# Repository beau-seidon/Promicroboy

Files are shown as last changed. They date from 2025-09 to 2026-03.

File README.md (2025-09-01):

# Arduinoboy (b_s)
~~Official~~ ArduinoBoy Repository for serial MIDI communication to the Nintendo Gameboy.

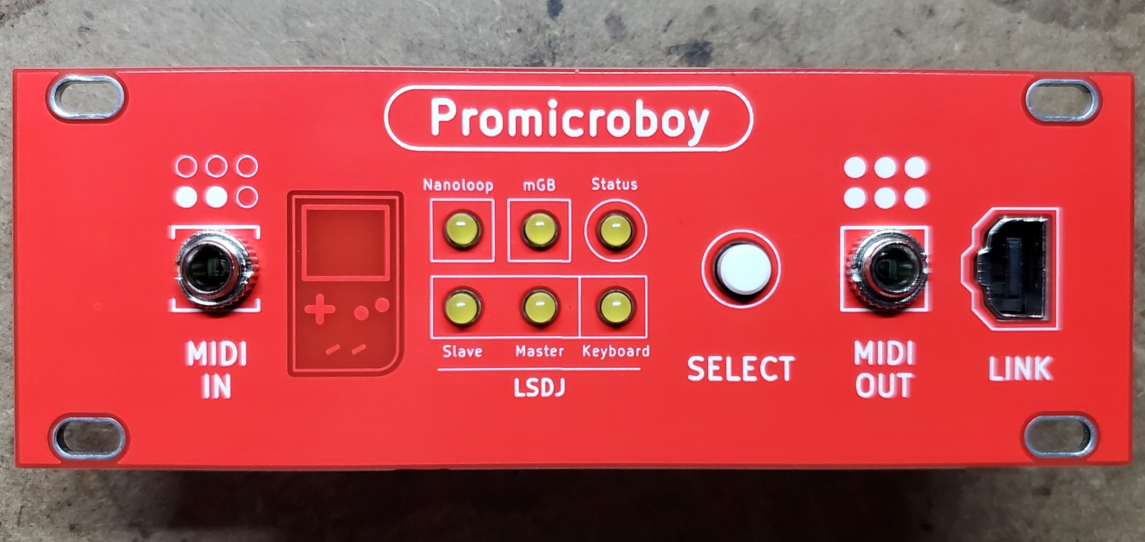
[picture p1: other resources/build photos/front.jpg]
Promicroboy


### The readme below is still based on the original repo, updates coming soon!
See changelog for more info.



## About
Arduinoboy is software for the [Arduino hardware platform](http://arduino.cc) that allows serial communication (MIDI) to the Nintendo Gameboy for music applications such as [LittleSoundDJ](http://littlesounddj.com), [Nanoloop.](http://www.nanoloop.com/), and [mGB](https://github.com/trash80/mGB)

## Current Features
* Affordable and easily accessible parts for assembly.
* Accurate MIDI Sync, Start and Stop commands.
* Push Button selector sets the sync/state modes [(7 modes available)](#modes-details)
* [mGB](https://github.com/trash80/mGB)
 Mode: Full MIDI in support across all Gameboy Channels, including a unique "poly" mode allows you to play your Game Boy like a synthesizer.
* Midi Out Doubles as a Midi Thru
* "Filtering" data for only sync messages, no dedicated MIDI line required.
* Can be powered by the Game Boy's gamelink port.
* USB upgradeable via Arduino.
* Midi settings configurable using a Mac/PC editor built in Max.
* Tested and works with DMG (Original), Gameboy Color, and Advance/SP.

## Modes Details
#### Mode 1 - LSDJ as MIDI Slave Sync
Slave your Game Boy running [LittleSoundDJ](http://littlesounddj.com) to your midi sequencer or Digital audio workstation.

You can send the arduinoboy midi notes to change sync resolution and start/stop the LSDJ sequencer.

_LSDJ Slave Mode Midi Note Effects:_

* 48 - `C-2` Sends a Sequencer Start Command
* 49 - `C#2` Sends a Sequencer Stop Command
* 50 - `D-2` Toggles Normal Tempo
* 51 - `D#2` Toggles 1/2 Tempo
* 52 - `E-2` Toggles 1/4 Tempo
* 53 - `F-2` Toggles 1/8 Tempo

Higher note values than these map LSDJ song position row offset on a Song Start.

In LSDJ the `sync` mode should be set to `Slave`

#### Mode 2 LSDJ as MIDI Master Sync.

Send Midi sync with LSDJ as a midi clock master, LSDJ also sends a Midi Note on message that corresponds to the song row number on play.

In LSDJ the `sync` mode should be set to `Master`

#### Mode 3 LSDJ PC Keyboard mode.
This mode emulates the [PC Keyboard Mode](http://littlesounddj.wikia.com/wiki/PC_Keyboard_Interface) built into LSDJ, allowing you to control the following aspects of LSDJ:

Features:

* The first octave controls M-U-T-E,
* Cursor control (LSDJ Live mode only),
* Table selection
* Table cue.

_PC Keyboard mode midi note map_

* 36 - `C-1` Mute Pu1 Off/On
* 37 - `C#1` Mute Pu2 Off/On
* 38 - `D-1` Mute Wav Off/On
* 39 - `D#1` Mute Noi Off/On
* 40 - `E-1` Livemode Cue Sequence
* 41 - `F-1` Livemode Cursor Up
* 42 - `F#1` Livemode Cursor Down
* 43 - `G-1` Livemode Cursor Left
* 44 - `G#1` Live mode Cursor Right
* 45 - `A-1` Table Up
* 46 - `A#1` Table Down
* 47 - `B-1` Cue Table
* 48+ - Notes from this note up will accept midi in from an external keyboard or sequencer and allow you to play the notes`C-2 to C-8`.
* Midi Program Change messages will select from instrument table
* Default Midi channel is 16. You can set this in the top of the main source file in the archive, or via the [Max Pat editor](#max).

In LSDJ the `sync` mode should be set to `Keyboard`

#### Mode 4 MIDI to Nanoloop sync
Sync [Nanoloop.](http://www.nanoloop.com/) to external midi clock signals sent to the midi in.

In Nanoloop, the sync mode should be set to `slave`.

#### Mode 5 Full MIDI with mGB
[mGB](https://github.com/trash80/mGB) is a Gameboy cartridge program (You need a Flash Cart and Transfer hardware) That enables the Gameboy to act as a MIDI supported sound module that allows full control of the Game Boy sound hardware.

It works with the old DMG Gameboy as well as GBC/GBA.

#### Mode 6 LSDJ MIDIMAP
Lsdj will sync to incoming MIDI sync, and incoming MIDI notes are mapped to LSDJ's song row #. The currently selected row's MIDI note is displayed on the top right of the LSDJ screen, and incoming MIDI notes will also display the relative song row number in the same location.

In LSDJ the `sync` mode should be set to `MI.MAP`.

*This requires a special version of LSDJ, which can be found in your account on the [LSDJ website](http://littlesounddj.com/lsd/latest/full_version/).*

#### Mode 7 LSDJ MIDIOUT
Each of the 4 gameboy channels send MIDI data on 4 midi channels by the use of effects commands:

* `Nxx` - Sends a MIDI Note - Absolute to the value placed in the effect. N00 sends note off, `N01`-`N6F` send midi notes 1 to 112.
* `Qxx` - Sends a [MIDI Note](http://www.electronics.dit.ie/staff/tscarff/Music_technology/midi/midi_note_numbers_for_octaves.htm) relative to the current channel's pitch. The effect value is a offset. so `Q0C` in `PU1` would send a note 1 octave higher than what `PU1` is currently playing. This is useful as a table command to track midi notes as normal notes in the sequencer.
* `Xxx` - Sends a MIDI CC - By default in Arduinoboy the high nibble selects a CC#, and the low nibble sends a value `0-F` to `0-127`. This can be changed to allow just 1 midi CC with a range of `00`-`6F`, or 7 CCs with scaled or unscaled values.
* `Yxx` - Sends a program/patch/preset change.

By default each channel of LSDJ is mapped to midi channels 1-4. For example note commands from PU1 will be sent to midi channel 1.

In LSDJ the `sync` mode should be set to `Midiout`.

*This requires a special version of LSDJ, which can be found in your account on the [LSDJ website](http://littlesounddj.com/lsd/latest/full_version/).*

## Max Editor
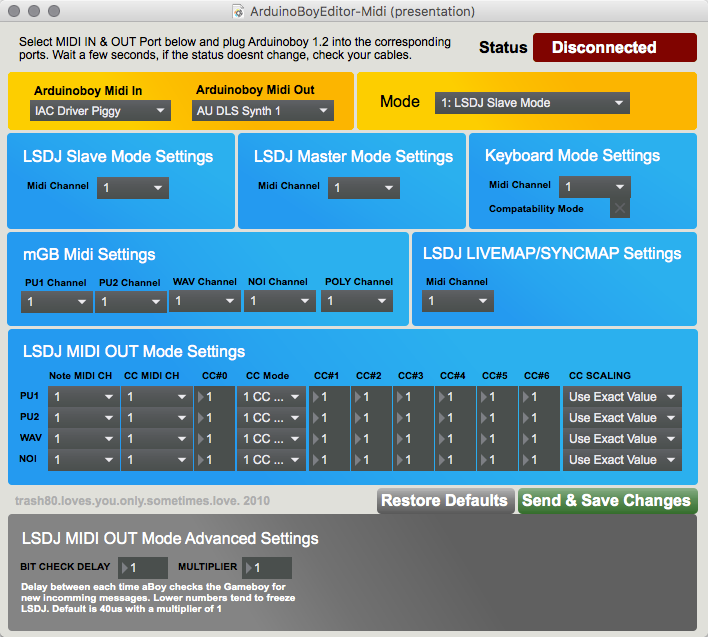
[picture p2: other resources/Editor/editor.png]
Editor gui

[The Arduinoboy Editor for Max](https://github.com/trash80/Arduinoboy/tree/master/Editor) for PC/OSX machines is a gui editor that allows you to edit the various global midi settings of your arduinoboy without editing or flashing code, over midi. It used to required the now deprecated Max Runtime, but you can also run it using a demo of [Cycling '74's Max application](https://cycling74.com/downloads/)

### Maxpat Settings
* `Midi In/Out`
Connect your arduinoboy to these ports on your system. Once it has connected, all the lights on your arduinoboy should flash in order, and the editor will show a green `Connected`.
* `Mode`
Setting this will tell your arduinoboy what mode to boot into automatically. This is handy if you built your own arduinoboy and decided you wanted to skimp out on LEDs and a button.
* `LSDJ Slave Mode settings` - The midi channel LSDJ slave mode will receive its commands on.
* `LSDJ Master Mode settings` - The midi channel LSDJ Master mode will send its midi notes mapped to row number on.
* `Keyboard Mode settings` - What channel LSDJ will look for its keyboard mode midi commands. No idea what compatibility mode does.
* `mGB midi settings` - Map each incoming midi channel to a specific Gameboy channel in mGB.
* `LSDJ Livesync/Livemap settings` - The midi channel Livesync/Livemap will listen to incoming midi commands from.
* `LSDJ Midiout settings` - Here you can set the following:
	* `Note midi channel` -  The channel each LSDJ channel will send it's midi note commands on.
	* `CC midi channel` -  The channel each LSDJ channel will send it's Continuous Controller commands on.
	* `CC 0` - The initial CC each channel will send. The type of data it will send is based on the next setting.
	* `CC Mode` - Game Boys have limitations! You can either have arduinoboy send one CC with many values, or 7 with limited 8bit values. By default in Arduinoboy the high nibble selects a CC#, and the low nibble sends a value [0-F] to [0-127]. This can be changed to allow just 1 midi CC with a range of 00-6F, or 7 CCs with scaled or unscaled values.
	* `CC Scaling ` - Set wether the 7 CCs are scaled or unscaled.

## Future Features & wishlist
  * Build instructions, and a Arduino Shield

## How To build an Arduinoboy



* [Build Photos](http://flickr.com/photos/trash80/2316803175/in/set-72157604068871573/)
* [Old version (Pre 1.1.0)](http://trash80.net/junkfood/arduinoboy/arduinoboy-schem-v.0.9.8-r1.png)

### Video Demos

  * [Keyboard Mode Test](http://youtube.com/watch?v=TnLUuvc78XY)
  * [Sync Demos](http://youtube.com/watch?v=iVmhy-Lo7BI)
  * [Arduino inside of Gameboy DMG](http://youtube.com/watch?v=VwrMuOA0VnY)
  * [mGB Example & Arduinoboy build into a DMG](http://vimeo.com/1853931)
  * [PDF explores mGB with a MIDI guitar](http://www.youtube.com/watch?v=HAU9MzZ2qeE)

## Thanks To
  * [Arduino](http://arduino.cc)
  * [Nitro2k01](http://blog.gg8.se/wordpress/) for ASM help with mGB
  * [GWEM](http://www.preromanbritain.com/gwem/lsdj_midi/g33k.html) g33k page
  * [Midines](http://wayfar.net) Thanks for the help x|k!
  * [firestARTer](http://www.firestarter-music.de) help with keyboard & Midi handling information.
  * [Gijs Gieskes](http://gieskes.nl) Found source code that gave insight into Nanoloop sync
  * [Little Sound DJ](http://littlesounddj.com)
  * [http://devrs.com/gb](http://devrs.com/gb) Madcatz PC link port for gb serial specs
  * [http://chipmusic.org](http://chipmusic.org) For all things Chipmusic.

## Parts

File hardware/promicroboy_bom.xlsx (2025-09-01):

REF | QTY | VAL | MOUSER | OTHER
C1 | 1 | 0.47 uF | 603-CC805JRNPO9BN471 (https://www.mouser.com/ProductDetail/603-CC805JRNPO9BN471)
C2 | 1 | 22 uF | 187-CL31A226KAHNNNE (https://www.mouser.com/ProductDetail/187-CL31A226KAHNNNE)
D1-D6 | 6 | 3 mm, yellow | 710-151031YS06000 (https://www.mouser.com/ProductDetail/710-151031YS06000)
D7 | 1 | 1N4148W | 833-1N4148W-TP (https://www.mouser.com/ProductDetail/833-1N4148W-TP)
J1-J2 | 2 | 3.5 mm TRS |  | PJ366ST/ WQP518MA (stereo)/ PJ398SM (https://www.thonk.co.uk/shop/thonkiconn/)
J3 | 1 | 02x05, male | 710-61301021121 (https://www.mouser.com/ProductDetail/710-61301021121)
J4a | 1 | 01x06, male, right-angle | 649-68015-406HLF (https://www.mouser.com/ProductDetail/649-68015-406HLF)
J4b | 1 | GB Link Port |  | Link Port (https://handheldlegend.com/products/game-boy-advance-ext-link-port)
R1-R4 | 4 | 220R | 603-RC0805FR-07220RL (https://www.mouser.com/ProductDetail/603-RC0805FR-07220RL)
R5 | 1 | 4.7K | 603-RC0805FR-074K7L (https://www.mouser.com/ProductDetail/603-RC0805FR-074K7L)
R6 | 1 | 2K | 603-RC0805FR-072KL (https://www.mouser.com/ProductDetail/603-RC0805FR-072KL)
R7-R12 | 6 | 1K | 603-RC0805FR-071KL (https://www.mouser.com/ProductDetail/603-RC0805FR-071KL)
SW1a | 1 | 6 mm | 612-105SPF100Q1RBLK (https://www.mouser.com/ProductDetail/612-105SPF100Q1RBLK)
SW1b | 1 | Round White | 612-1RWHT (https://www.mouser.com/ProductDetail/612-1RWHT)
U1a | 1 | ProMicro, 5v, 16MHz |  | Sparkfun ProMicro 5V 16MHz (https://www.sparkfun.com/pro-micro-5v-16mhz.html)
U1b | 2 | 01x12, female |  | Female Headers (https://www.sparkfun.com/female-headers.html)
U2a | 1 | 6N138 | 859-6N138 (https://www.mouser.com/ProductDetail/859-6N138)
U2b | 1 | PDIP8 | 571-2485264-1 (https://www.mouser.com/ProductDetail/571-2485264-1)
U3 | 1 | +8 VDC | 926-LM2940IMPX80NOPB (https://www.mouser.com/ProductDetail/926-LM2940IMPX80NOPB)

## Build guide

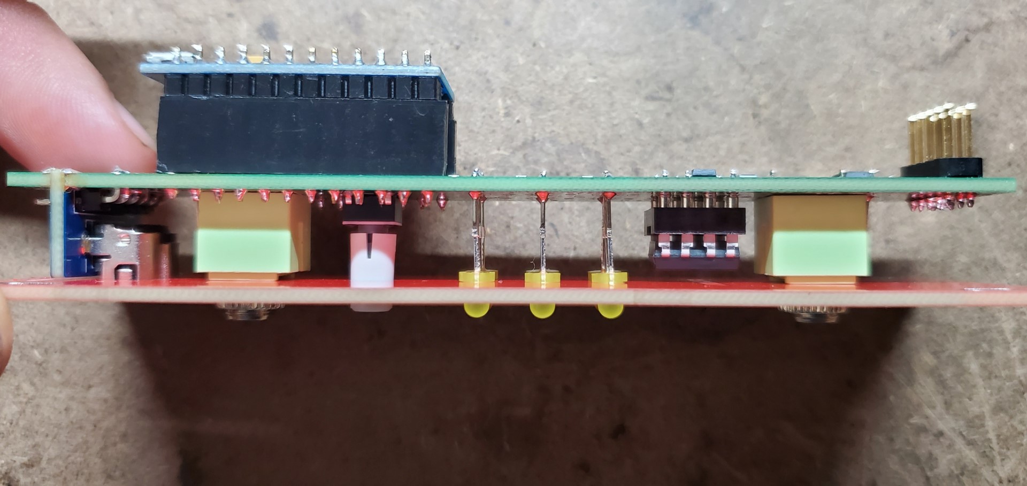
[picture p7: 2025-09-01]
other resources/build photos/side.jpg

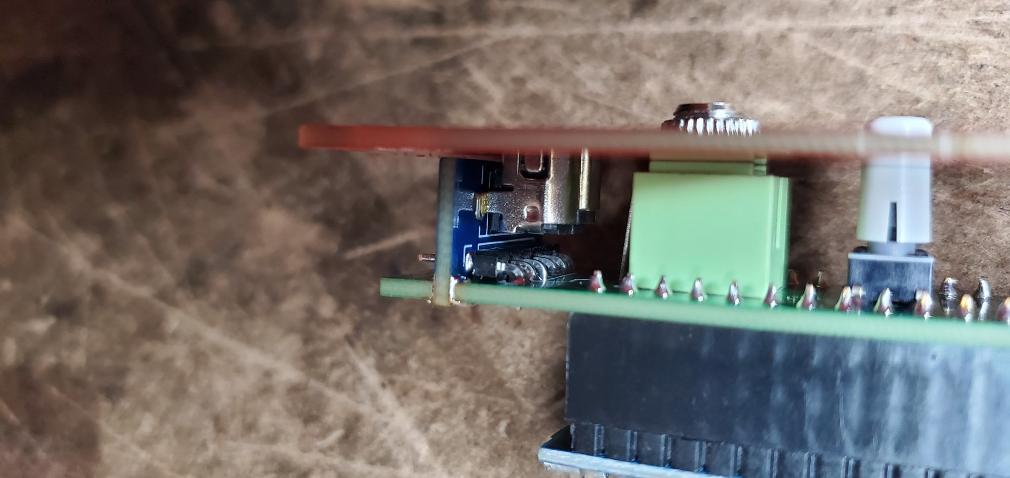
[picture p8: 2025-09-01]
other resources/build photos/link1.jpg

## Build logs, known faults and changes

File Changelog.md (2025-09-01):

## Changelog

### 08/31/25
* Arduinoboy to version "1.4.1"
* Created Promicroboy eurorack module. Available in 3U 4HP, or 1U (Intellijel) 22HP. KiCad files, gerbers, and bom are provided. Will upload build photos soon.
* Rearranged project files to my own preferred format.
* WIP: manually merging latest commits from [tstirrat](https://github.com/tstirrat/Arduinoboy) and [Chiptune-Anamnesis](https://github.com/Chiptune-Anamnesis/Arduinoboy_Main). not finished, don't try to build the firmware from this commit :)

### 05/18/24
* Arduinoboy to version "1.4.0"
* Converted repo to work with PlatformIO for all supported boards. Unfortunately this broke compatibility with ArduinoIDE, since it uses .cpp and .h files instead of .ino.
* Refactored all source for readability and consistency.
* Fixed a few build errors.

### 05/19/20
* Arduinoboy to version 1.3.4
* Added support for Arduino Mega 2560 and Arduino UNO Wifi

### 05/17/20
* Arduinoboy to version 1.3.3
* Added support for Arduino Due

### 05/03/20
* Arduinoboy to version 1.3.2
* Added support for Arduino Leonardo/Yún/Micro (ATmega32U4) (only Leonardo tested)

### 04/19/20
* Arduinoboy to version 1.3.1
* Fixed Nanoloop sync through USB (teensy and Leonardo tested)

### 07/10/16
* New Version 1.3.0a, please download from the [Releases] (https://github.com/trash80/Arduinoboy/releases) if you want the most recent stable version.
* Added Teensy 3.x & LC support. Check the main file for the pin configuration.
* Added USB MIDI support for Teensy
* Updated LSDJ LIVEMAP / SYNCMAP mode. This only works with LSDJ Arduinoboy version 4.8.7 and above. Licensed users can [download it here](http://littlesounddj.com/lsd/latest/full_version/lsdj4_8_7-arduinoboy.zip) Livemap has been removed in favor of stable sync slave mode.

### 06/26/15
* Project has been moved to GitHub. mGB has been moved to it's own project [Available here](https://github.com/trash80/mGB)

### 12/23/11
* Arduinoboy to version 1.2.3
* Fixed code to work in Arduino 1.0 Software.

### 09/14/11
   * Arduinoboy to version 1.2.2
   * Fixed bug in mGB mode causing the Arduinoboy to respond to other MIDI channels besides the ones assigned to mGB.

### 04/03/11
   * Arduinoboy to version 1.2.0
   * Added EEPROM based settings to all modes which include reassigning MIDI channels in mGB
   * Created software editor for Arduinoboy settings. The file is in the zip and requires the free Max Runtime: http://cycling74.com/downloads/
   * Added 2 new Modes that require a new version of LSDJ. There is a unofficial release of LSDJ which supports these new modes, available here: http://littlesounddj.com/lsd/latest/full_version
      * LIVEMAP / SYNCMAP
       * LIVEMAP - Lsdj will use its own clock, but a incoming midi note will cue midi note # to song row # in live mode.
       * SYNCMAP - Lsdj will sync to incoming MIDI sync, and notes immediately change the song row #.
      * MIDIOUT - LSDJ to MIDIOUT. Each of the 4 gameboy channels send MIDI data on 4 midi channels by the use of effects commands:
       * N - Sends a MIDI Note - Absolute to the value placed in the effect. N00 sends note off, N01-N6F send notes 1 to 112.
       * Q - Sends a MIDI Note relative to the current channel's pitch. The effect value is a offset. so Q0C in PU1 would send a note 1 octave higher than what Pu1 is currently playing. This is useful as a table command to track midi notes as normal notes in the sequencer.
       * X - Sends a MIDI CC - By default in Arduinoboy the high nibble selects a CC#, and the low nibble sends a value [0-F] to [0-127]. This can be changed to allow just 1 midi CC with a range of 00-6F, or 7 CCs with scaled or unscaled values.
       * Y - Sends a program/patch/preset change.

### 02/07/09
* Arduinoboy to version 1.1.0
* Changed Gameboy Pins to the Arduino's "Analog In" pins. From  the old version's 5,6,7 to A0,A1,A2. This allows better more stable behavior. View the source file for changes. And the new "schematic" at the bottom of the page.

### 02/02/09
   * mGB to version 1.3.0
     * Rewrote 90% of code into assembly for much faster performance- especially noticeable on DMG.
     * Changed note behavior. Removed Monophonic note memory to increase performance.
     * Envelope does not retrigger if the notes overlap and have the same velocity- Good for arpeggios / broken chords.
     * Note off has a slight delay so immediate retrigged notes don't cause "clicking" effect due to turning off the synth.
     * Added screen off mode for great signal-to-noise ratio, longer battery life, and better performance on DMG. (To toggle the screen mode hold Select and press A.)
     * Created back-end routine that prioritizes processes for better performance.
     * Added 8 "noise" shapes to the Wav synth for more interesting effects.
     * Made Wav pitch sweep stable and changed it so it glitches out at values above 8. :D

### 11/05/08
   * New Google group created for Arduinoboy and mGB. http://groups.google.com/group/arduinoboy
   * New Flickr Group. Share your Arduinoboy pics. :) http://flickr.com/groups/arduinoboy
   * mGB to version 1.2.4
    * Fixed small bug with the indicator arrow, it was offset vertically a bit.
    * Fixed bug with unexpected behavior with large PB Ranges
    * PB Range Max is now 48 notes. (hehe)
    * Octave Shift max is now -2/+3
    * Added some Octave shift logic. If the current note is greater than what the GB can play due to octave shifting, it will select the lower octave note, so no off key notes will play.
    * Added Gameboy Color fast-cpu mode- better performance with newer Gameboys.

### 10/28/08
* mGB to version 1.2.3
    * Added Note markers above synth number, so you can tell if the synth is on. ;)
    * Added PB wheel reset to MIDI panic (Start button)
    * Code more efficient (I'm sure there is still more to do here)
    * nitro2k01 @ http://gameboygenius.8bitcollective.com rewrote my gamejack serial function to make it as fast as possible. THANKS!!
   * Arduinoboy 1.0.5 yet again its just a release to work with mGB 1.2.3 - Everytime the code is sped up on mGB, I remove some delay in Arduinoboy to make the communication faster. This is why you always see a update of Arduinoboy with mGB

### 10/25/08
   * Added Program Change messages to mGB
   * Rewrote MIDI data input for mGB. (Rewrote the function in ASM to make it faster)
   * Added Controller Priority. While changing parameters on the gameboy itself, MIDI messages will not overwrite your changes while your editing them. This is a good live mode feature
   * Arduinoboy code updated yet again for mGB behavior. Arduinoboy release will now always be included in a zip file inside the mGB zip so you know that the version of Arduinoboy thats included with the mGB archive is the one to use.

### 10/23/08
   * Found & Fixed various bugs in 1.2.0
   * Changed help text. Made it more clear.

### 10/23/08
   * Added preset load/save memory to mGB. 16 Storage slots for each synth. Recalled via interface or by Midi CC 5 for now, I want to add program change message but would require further rewrites. Check the information below for mGB usage.
   * mGB is now rock solid stable *(It needs Arduinoboy 1.0.3 to work properly)*
   * Changed mGB interface to use less sprites, as a result the look has changed.
   * Arduinoboy 1.0.3 has better behavior for mGB 1.2.0 but should also work better for old mGB versions as well.

### 10/20/08
   * Added interface to mGB.
   * Changed WAV CC Parameters
   * Arduinoboy 1.0.2 has better behavior for mGB 1.1.0

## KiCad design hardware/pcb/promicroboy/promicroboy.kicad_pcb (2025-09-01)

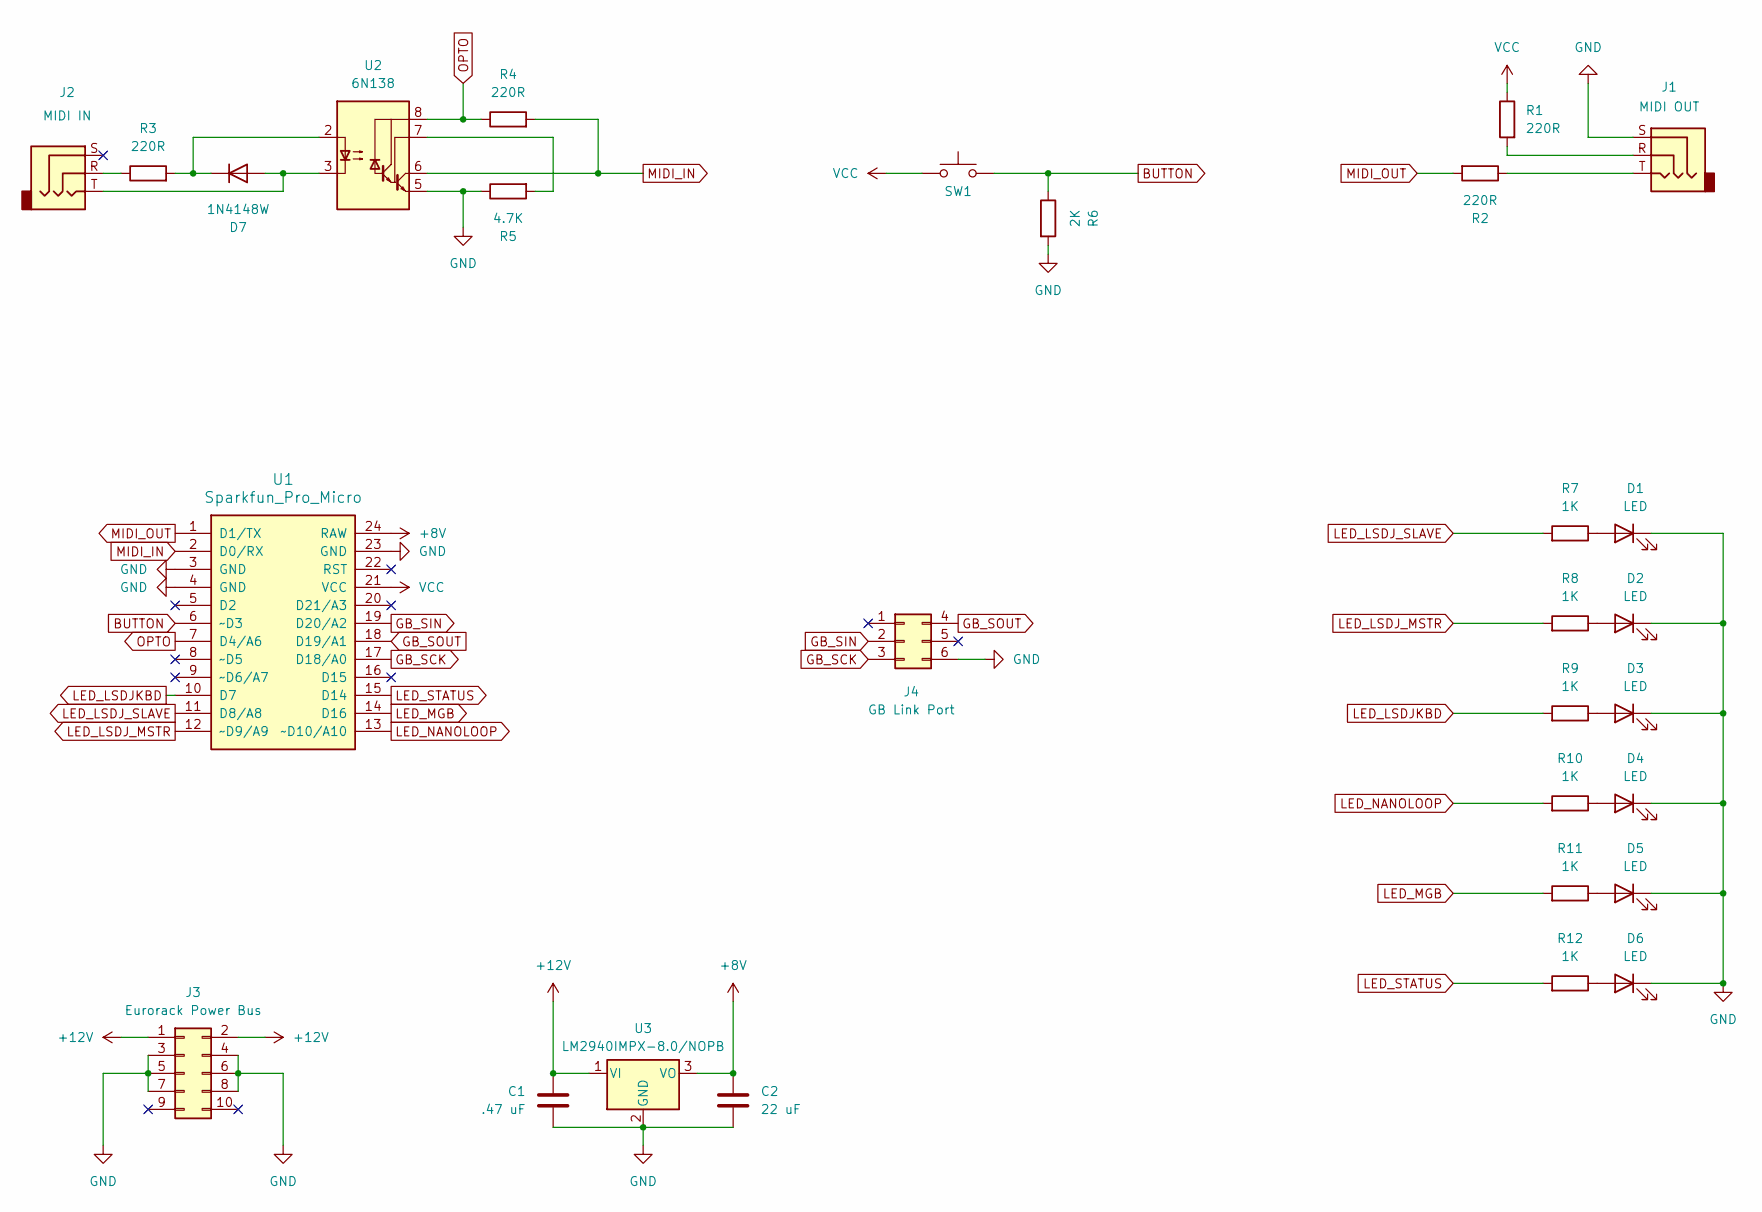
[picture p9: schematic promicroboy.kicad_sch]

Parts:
C1: .47 uF; C_0805_2012Metric_Pad1.18x1.45mm_HandSolder
C2: 22 uF; C_1206_3216Metric_Pad1.33x1.80mm_HandSolder
D1, D2, D3, D4, D5, D6: LED; LED_D3.0mm
D7: 1N4148W; D_SOD-123
J1: MIDI OUT; Jack_3.5mm_QingPu_WQP-PJ398SM_Vertical_CircularHoles_TRS
J2: MIDI IN; Jack_3.5mm_QingPu_WQP-PJ398SM_Vertical_CircularHoles_TRS
J3: Eurorack Power Bus; PinHeader_2x05_P2.54mm_Vertical
J4: GB Link Port; PinSocket_1x06_P2.54mm_Vertical
R1, R2, R3, R4: 220R; R_0805_2012Metric_Pad1.20x1.40mm_HandSolder
R5: 4.7K; R_0805_2012Metric_Pad1.20x1.40mm_HandSolder
R6: 2K; R_0805_2012Metric_Pad1.20x1.40mm_HandSolder
R7, R8, R9, R10, R11, R12: 1K; R_0805_2012Metric_Pad1.20x1.40mm_HandSolder
SW1: SW_Push; SW_PUSH_6mm
U1: Sparkfun_Pro_Micro
U2: 6N138; DIP-8_W7.62mm_Socket
U3: LM2940IMPX-8.0/NOPB; SOT-223-3_TabPin2

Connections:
+8V: C2.1, U1.24 (RAW), U3.3 (VO)
+12V: C1.1, J3.1, J3.2, U3.1 (VI)
BUTTON: R6.1, SW1.1, U1.6 (~D3)
GB_SCK: J4.3 (SCK), U1.17 (D18/A0)
GB_SIN: J4.2 (SIN), U1.19 (D20/A2)
GB_SOUT: J4.4 (SOUT), U1.18 (D19/A1)
GND: C1.2, C2.2, D1.1 (K), D2.1 (K), D3.1 (K), D4.1 (K), D5.1 (K), D6.1 (K), J1.S, J3.3, J3.4, J3.5, J3.6, J3.7, J3.8, J4.6 (GND), R5.1, R6.2, U1.3 (GND), U1.4 (GND), U1.23 (GND), U2.5 (GND), U3.2 (GND)
LED_LSDJKBD: R9.2, U1.10 (D7)
LED_LSDJ_MSTR: R8.2, U1.12 (~D9/A9)
LED_LSDJ_SLAVE: R7.2, U1.11 (D8/A8)
LED_MGB: R11.2, U1.14 (D16)
LED_NANOLOOP: R10.2, U1.13 (~D10/A10)
LED_STATUS: R12.2, U1.15 (D14)
MIDI_IN: R4.2, U1.2 (D0/RX), U2.6 (VO2)
MIDI_OUT: R2.2, U1.1 (D1/TX)
unnamed: D1.2 (A), R7.1
unnamed: D2.2 (A), R8.1
unnamed: D3.2 (A), R9.1
unnamed: D4.2 (A), R10.1
unnamed: D5.2 (A), R11.1
unnamed: D6.2 (A), R12.1
unnamed: D7.2 (A), J2.T, U2.3 (C2)
unnamed: D7.1 (K), R3.2, U2.2 (C1)
unnamed: J1.R, R1.2
unnamed: J1.T, R2.1
unnamed: J2.R, R3.1
unnamed: R5.2, U2.7 (VO1)
OPTO: R4.1, U1.7 (D4/A6), U2.8 (VCC)
VCC: R1.1, SW1.2, U1.21 (VCC)

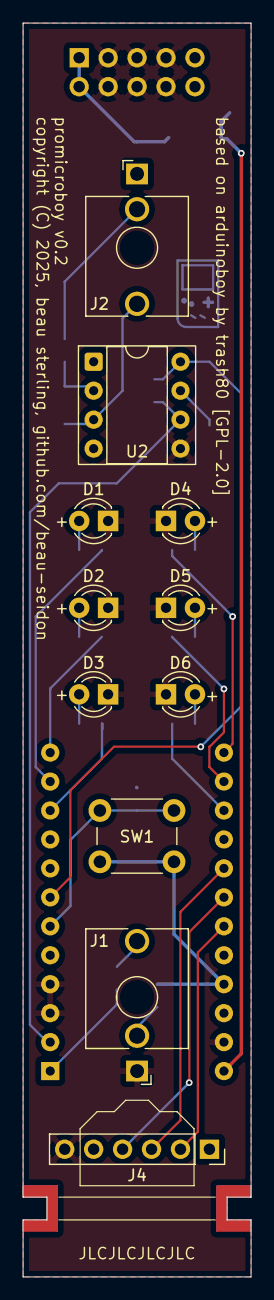
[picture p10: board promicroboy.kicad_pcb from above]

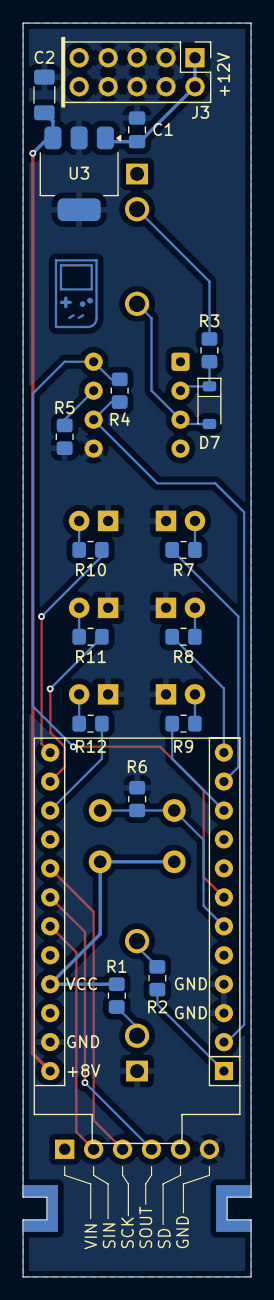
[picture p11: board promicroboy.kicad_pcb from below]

Board: 2 copper layers, 20.0 x 110.0 mm, 29 parts (18 on the bottom side), 29 nets.

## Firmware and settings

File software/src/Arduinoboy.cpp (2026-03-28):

/***************************************************************************
 ***************************************************************************
 *                         __      _             __                        *
 *         ____ __________/ /_  __(_)___  ____  / /_  ____  __  __         *
 *        / __ `/ ___/ __  / / / / / __ \/ __ \/ __ \/ __ \/ / / /         *
 *       / /_/ / /  / /_/ / /_/ / / / / / /_/ / /_/ / /_/ / /_/ /          *
 *       \__,_/_/   \__,_/\__,_/_/_/ /_/\____/_.___/\____/\__, /           *
 *                                                       /____/            *
 *                                                                         *
 ***************************************************************************
 ***************************************************************************
 *                                                                         *
 *  Version:             1.4.0                                             *
 *  Date:                March 20 2026                                     *
 *  Name:                Beau Sterling (beau-seidon)                       *
 *  Email:               aether.soundlab@outlook.com                       *
 *                                                                         *
 *  Modified by:         tstirrat & crunchypotato                          *
 *                                                                         *
 *  Original Creator:    Timothy Lamb                                      *
 *  Email:               trash80@gmail.com                                 *
 *                                                                         *
 ***************************************************************************
 ***************************************************************************
 *                                                                         *
 *  NOTICE NOTICE NOTICE NOTICE NOTICE NOTICE NOTICE NOTICE NOTICE NOTICE  *
 *                                                                         *
 *  https://github.com/trash80/Arduinoboy                                  *
 *                                                                         *
 *  Arduino pin settings:  (Layout is final)                               *
 *      - 6 LEDS on pins 8 to 13                                           *
 *      - Push button on pin 3 (for selecting mode)                        *
 *      - MIDI Opto-isolator power on pin 4                                *
 *      - Gameboy Clock line on analog in pin 0                            *
 *      - Gameboy Serial Data input on analog in pin 1                     *
 *      - Serial Data from gameboy on analog in pin 2                      *
 *                                                                         *
 *  Teensy pin settings:                                                   *
 *      - 6 LEDS on pins 23, 22, 21, 20, 4, 13                             *
 *      - Push button on pin 2 (for selecting mode)                        *
 *      - MIDI Opto-isolator power connected to +3v                        *
 *      - Gameboy Clock line on pin 16                                     *
 *      - Gameboy Serial Data input on analog in pin 17                    *
 *      - Serial Data from gameboy on analog in pin 18                     *
 *                                                                         *
 *   Teensy USB MIDI is supported                                          *
 *   Teensy LC should work but untested                                    *
 *                                                                         *
 *  Program Information:                                                   *
 *      LSDJ Slave Mode Midi Note Effects:                                 *
 *          48 - C-2 Sends a Sequencer Start Command                       *
 *          49 - C#2 Sends a Sequencer Stop Command                        *
 *          50 - D-2 Toggles Normal Tempo                                  *
 *          51 - D#2 Toggles 1/2 Tempo                                     *
 *          52 - E-2 Toggles 1/4 Tempo                                     *
 *          53 - F-2 Toggles 1/8 Tempo                                     *
 *                                                                         *
 *      LSDJ Keyboard Mode:                                                *
 *          48 - C-2 Mute Pu1 Off/On                                       *
 *          49 - C#2 Mute Pu2 Off/On                                       *
 *          50 - D-2 Mute Wav Off/On                                       *
 *          51 - D#2 Mute Noi Off/On                                       *
 *          52 - E-2 Livemode Cue Sequence                                 *
 *          53 - F-2 Livemode Cursor Up                                    *
 *          54 - F#2 Livemode Cursor Down                                  *
 *          55 - G-2 Livemode Cursor Left                                  *
 *          56 - G#2 Livemode Cursor Right                                 *
 *          57 - A-2 Table Up                                              *
 *          58 - A#2 Table Down                                            *
 *          59 - B-2 Cue Table                                             *
 *          60 - C-3 to C-8 Notes!                                         *
 *          Prgram Change to select from instrument table                  *
 *                                                                         *
 ***************************************************************************/
/***************************************************************************
 *                                                                         *
 *  This program is free software; you can redistribute it and/or modify   *
 *  it under the terms of the GNU General Public License as published by   *
 *  the Free Software Foundation; either version 2 of the License, or      *
 *  (at your option) any later version.                                    *
 *                                                                         *
 ***************************************************************************/

#include "Arduinoboy.h"

#include "Led_Functions.h"
#include "Memory_Functions.h"
#include "Mode_Programmer.h"
#include "Mode.h"


/***************************************************************************
* User Settings
***************************************************************************/
boolean usbMode = false;        // to use usb for serial communication as opposed to MIDI - sets baud rate to 38400

byte defaultMemoryMap[MEM_MAX] = {
    0x7F, 0x01, 0x04, 0x7F,     // memory init check
    0x00,                       // force mode (forces lsdj to be sl)
    0x00,                       // mode

    15,                         // sync effects midi channel (0-15 = 1-16)
    15,                         // masterNotePositionMidiChannel - LSDJ in master mode will send its song position on the start button via midi note. (0-15 = 1-16)

    15,                         // keyboardInstrumentMidiChannel - midi channel for keyboard instruments in lsdj. (0-15 = 1-16)
    1,                          // Keyboard Compatability Mode
    1,                          // Set to true if you want to have midi channel set the instrument number / doesnt do anything anymore

    0, 1, 2, 3,                 // midiOutNoteMessageChannels - midi channels for lsdj midi out note messages Default: channels 1, 2, 3, 4
    0, 1, 2, 3,                 // midiOutCCMessageChannels - midi channels for lsdj midi out CC messages Default: channels 1, 2, 3, 4
    1, 1, 1, 1,                 // midiOutCCMode - CC Mode, 0 = use 1 midi CC, with the range of 00-6F, 1 = uses 7 midi CCs with the
                                // range of 0-F (the command's first digit would be the CC#), either way the value is scaled to 0-127 on output
    1, 1, 1, 1,                 // midiOutCCScaling - CC Scaling- Setting to 1 scales the CC value range to 0-127 as oppose to lsdj's incomming 00-6F (0-112) or 0-F (0-15)
    1, 2, 3, 7, 10, 11, 12,     // pu1: midiOutCCMessageNumbers - CC numbers for lsdj midi out, if CCMode is 1, all 7 ccs are used per channel at the cost of a limited resolution of 0-F
    1, 2, 3, 7, 10, 11, 12,     // pu2
    1, 2, 3, 7, 10, 11, 12,     // wav
    1, 2, 3, 7, 10, 11, 12,     // noi

    0, 1, 2, 3, 4,              // mGB midi channels (0-15 = 1-16)
    0,                          // sync map midi channel start (0-15 = 1-16) (for song rows 0x80 to 0xFF it's this channel plus 1)
    80, 1,                      // midiout bit check delay & bit check delay multiplier
    0, 0                        // midiout byte received delay & byte received delay multiplier
};
byte memory[MEM_MAX];


/***************************************************************************
* Lets Assign our Arduino Pins .....
***************************************************************************/
#if defined (__MK20DX256__) || defined (__MK20DX128__) || defined (__MKL26Z64__) || defined (__AVR_ATmega32U4__) || defined (PRO_MICRO)
    HardwareSerial* serial = &Serial1;
#elif defined (__SAM3X8E__)
    HardwareSerial* serial = &Serial;
#else
    HardwareSerial* serial = &Serial;
#endif


/***************************************************************************
* Memory
***************************************************************************/
#ifndef USE_DUE
    boolean alwaysUseDefaultSettings = false;    // set to true to always use the settings below, else they are pulled from memory for the software editor
#else
    boolean alwaysUseDefaultSettings = true;     // set to true to always use the default settings, in Due board is necessary as it doesn't have EEPROM
#endif

int eepromMemoryByte = 0;                        // Location of where to store settings from mem


/***************************************************************************
* Sysex Settings & vars
***************************************************************************/
boolean sysexReceiveMode = 0;
boolean sysexProgrammingMode = 0;
boolean sysexProgrammingConnected = 0;

const unsigned long PROGRAMMER_MAX_WAIT_TIME = 2000;    // 2 seconds
const unsigned long PROGRAMMER_MAX_CALL_TIME = 1000;    // 1 second
unsigned long sysexProgrammerLastResponse = 0;
unsigned long sysexProgrammerLastSent = 0;

const byte SYSEX_MFG_ID = 0x69;    // har har harrrrr :)
int sysexPosition;
byte sysexData[128];
byte longestSysexMessage = 128;

int midioutBitDelay = 0;
int midioutByteDelay = 0;


/***************************************************************************
* Switches and states
***************************************************************************/
boolean sequencerStarted = false;    // Sequencer has Started
boolean midiSyncEffectsTime = false;
boolean midiNoteOnMode = false;
boolean midiValueMode = false;

int midiOutLastNote[4] = {-1, -1, -1, -1};

boolean statusLedIsOn = false;
boolean statusLedBlink = false;

boolean nanoState = false;
boolean nanoSkipSync = false;

int buttonDepressed;

boolean blinkSwitch[6];
unsigned long int blinkSwitchTime[6];
uint8_t switchLight = 0;

uint16_t blinkMaxCount = 1000;

unsigned long midioutNoteTimer[4];
byte midioutNoteHold[4][4];
byte midioutNoteHoldCounter[4];
int midioutNoteTimerThreshold = 10;


/***************************************************************************
* Counter vars
***************************************************************************/
int countLSDJTicks = 0;    // for loop int (we need to cycle 8 pulses)
int countSyncTime = 0;
int countSyncLightTime = 0;
int countSyncSteps = 0;
int countSyncPulse = 0;
int countGbClockTicks = 0;
int countClockPause = 0;
int countStatusLedOn = 0;

int miscLastLed;
unsigned long int miscLedTime;
unsigned long int miscLedMaxTime;


/***************************************************************************
* Inbound Data Placeholders
***************************************************************************/

byte incomingMidiByte;    // incomming midi message
byte readgbClockLine;
byte readGbSerialIn;
byte bit;
byte midiData[] = {0, 0, 0};
byte lastMidiData[] = {0, 0, 0};

int incomingMidiNote = 0;
int incomingMidiVel = 0;
byte readToggleMode;
byte serialWriteBuffer[256];
byte midiDefaultStartOffset;
int writePosition = 0;
int readPosition = 0;
int lastMode = 0;    // Stores the last selected mode for leds.

byte midiSyncByte;
byte midiSyncByteLast;

byte midiStatusType;
byte midiStatusChannel;


/***************************************************************************
* LSDJ Keyboard mode settings
***************************************************************************/
byte keyboardNotes[] = {
    0x1A, 0x1B, 0x22, 0x23, 0x21, 0x2A, 0x34, 0x32, 0x33, 0x31, 0x3B, 0x3A,
    0x15, 0x1E, 0x1D, 0x26, 0x24, 0x2D, 0x2E, 0x2C, 0x36, 0x35, 0x3D, 0x3C
};

byte keyboardOctDn = 0x05;
byte keyboardOctUp = 0x06;

byte keyboardInsDn = 0x04;
byte keyboardInsUp = 0x0C;

byte keyboardTblDn = 0x03;
byte keyboardTblUp = 0x0B;

byte keyboardTblCue = 0x29;

byte keyboardMut1 = 0x01;
byte keyboardMut2 = 0x09;
byte keyboardMut3 = 0x78;
byte keyboardMut4 = 0x07;

byte keyboardCurL = 0x6B;
byte keyboardCurR = 0x74;
byte keyboardCurU = 0x75;
byte keyboardCurD = 0x72;
byte keyboardPgUp = 0x7D;
byte keyboardPgDn = 0x7A;
byte keyboardEntr = 0x5A;

int keyboardCurrentOct = 0;
int keyboardCurrentIns = 0;
int keyboardCurrentTbl = 0;

int keyboardLastOct = 0;
int keyboardLastIns = 0;
int keyboardLastTbl = 0;

int keyboardDiff = 0;
int keyboardCount = 0;
byte keyboardStartOctave = 0x24;
byte keyboardNoteStart = 0;
byte keyboardNoteOffset = 0;
byte keyboardCommands[12];


/***************************************************************************
* LSDJ Midi Map mode vars
***************************************************************************/
int mapCurrentRow = -1;
int mapQueueMessage = -1;
unsigned long mapQueueTime;
// mapQueueWait is used for delaying a sync byte
// if it is called right before a note on message on sequencer start
// (Note value is also a clock tick)
uint8_t mapQueueWaitSerial = 2;    // 2ms
uint8_t mapQueueWaitUsb = 5;       // 5ms - Needs to be longer because message packet is processed all at once


/***************************************************************************
* mGB Settings
***************************************************************************/


/***************************************************************************
* MIDI Setup (Serial and USB)
***************************************************************************/
USING_NAMESPACE_MIDI;

#ifdef HAS_USB_MIDI
    typedef USBMIDI_NAMESPACE::usbMidiTransport __umt;
    typedef MIDI_NAMESPACE::MidiInterface<__umt> __ss;
    __umt usbMIDI_t(0 /* cable no */);
    __ss uMIDI((__umt&)usbMIDI_t);
#endif

#if defined(ARDUINO_SAM_DUE) || defined(USBCON) || defined(__MK20DX128__) || defined(__MK20DX256__) || defined(__MKL26Z64__)
    MIDI_CREATE_INSTANCE(HardwareSerial, Serial1, sMIDI);
#else
    MIDI_CREATE_INSTANCE(HardwareSerial, Serial, sMIDI);
#endif


/***************************************************************************
*  Setup and Loop
***************************************************************************/
void setup()
{
    /* Init Memory */
    initMemory(0);

    /* Init Pins */
    for (int led = 0; led <= 5; led++) pinMode(pinLeds[led], OUTPUT);
    pinMode(pinStatusLed, OUTPUT);
    pinMode(pinButtonMode, INPUT);

    pinMode(pinGBClock, OUTPUT);
    pinMode(pinGBSerialIn, INPUT);
    pinMode(pinGBSerialOut, OUTPUT);

    /* Set MIDI Serial Rate */
    if (usbMode) {
        serial->begin(38400);
    } else {
        pinMode(pinMidiInputPower, OUTPUT);
        digitalWrite(pinMidiInputPower, HIGH);    // turn on the optoisolator
        sMIDI.begin(MIDI_CHANNEL_OMNI);

        // Enable serial MIDI in to serial MIDI out "thru mode"
        sMIDI.turnThruOn(Thru::Full);

        #ifdef HAS_USB_MIDI
            uMIDI.begin(MIDI_CHANNEL_OMNI);
        #endif
    }

    /* Set Pin States */
    digitalWrite(pinGBClock, HIGH);       // gameboy wants a HIGH line
    digitalWrite(pinGBSerialOut, LOW);    // no data to send

    /* Misc Startup */
    keyboardNoteStart = keyboardStartOctave + 12;    // Set the octave where the actual notes start (the octave below is for the mutes, cursor, etc)

    /* Assign the keyboard mode command array for the first octave */
    keyboardCommands[0] = keyboardMut1;
    keyboardCommands[1] = keyboardMut2;
    keyboardCommands[2] = keyboardMut3;
    keyboardCommands[3] = keyboardMut4;
    keyboardCommands[4] = keyboardCurL;
    keyboardCommands[5] = keyboardCurR;
    keyboardCommands[6] = keyboardCurU;
    keyboardCommands[7] = keyboardCurD;
    keyboardCommands[8] = keyboardEntr;
    keyboardCommands[9] = keyboardTblDn;
    keyboardCommands[10] = keyboardTblUp;
    keyboardCommands[11] = keyboardTblCue;

    /* Load Settings from EEPROM */
    #ifndef USE_DUE
        if (!memory[MEM_FORCE_MODE]) memory[MEM_MODE] = EEPROM.read(MEM_MODE);
    #endif
    lastMode = memory[MEM_MODE];

    initProgrammerSysexHandlers();

    startupSequence();

    showSelectedMode();    // Light up the LED that shows which mode we are in.
}


void loop ()    // Main Loop, which we don't use to be able to isolate each mode into its own setup and loop functions
{
    switchMode();
}

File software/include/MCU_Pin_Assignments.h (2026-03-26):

#pragma once

#include "Arduinoboy.h"


/***************************************************************************
* Lets Assign our Arduino Pins .....
***************************************************************************/


#if defined (__MK20DX256__) || defined (__MK20DX128__) || defined (__MKL26Z64__)
/***************************************************************************
* Teensy 3.2, Teensy LC
*
* Notes on Teensy: Pins are not the same as in the schematic, the mapping is below.
* Feel free to change, all related config in is this block.
* Be sure to compile
***************************************************************************/
    #include <USB-MIDI.h>

    #define USE_TEENSY
    #define HAS_USB_MIDI

    #if defined (__MKL26Z64__)
        #define GB_SET(bit_cl, bit_out, bit_in) GPIOB_PDOR = ((bit_in << 3) | (bit_out << 1) | bit_cl)
    #else
        #define GB_SET(bit_cl, bit_out, bit_in) GPIOB_PDOR = (GPIOB_PDIR & 0xfffffff4) | ((bit_in << 3) | (bit_out << 1) | bit_cl)
    #endif

    const int pinGBClock = 16;                        // Analog In 0 - clock out to gameboy
    const int pinGBSerialOut = 17;                    // Analog In 1 - serial data to gameboy
    const int pinGBSerialIn = 18;                     // Analog In 2 - serial data from gameboy
    const int pinMidiInputPower = 0;                  // Not used!
    const int pinStatusLed = 13;                      // Status LED
    const int pinLeds[] = {23, 22, 21, 20, 4, 13};    // LED Pins
    const int pinButtonMode = 2;                      // toggle button for selecting the mode


#elif defined (PRO_MICRO)
/***************************************************************************
* Pro Micro (ATmega32U4, with different pin config)
***************************************************************************/
    #include <USB-MIDI.h>

    #define USE_LEONARDO
    #define HAS_USB_MIDI

    #define GB_SET(bit_cl, bit_out, bit_in) PORTF = (PINF & B00011111) | ((bit_cl << 7) | (bit_out << 6) | (bit_in << 5))
    // ^ The reason for not using digitalWrite is to align clock and data pins for the GB shift reg.
    // Pin distribution comes from official Arduino Leonardo documentation

    const int pinGBClock = A0;                      // Analog In 0 - clock out to gameboy
    const int pinGBSerialOut = A1;                  // Analog In 1 - serial data to gameboy
    const int pinGBSerialIn = A2;                   // Analog In 2 - serial data from gameboy
    const int pinMidiInputPower = 4;                // power pin for midi input opto-isolator
    const int pinStatusLed = 14;                    // Status LED
    const int pinLeds[] = {8, 9, 7, 10, 16, 14};    // LED Pins
    const int pinButtonMode = 3;                    // toggle button for selecting the mode

    // for the broken Promicroboy pcb: flip A1 and A2 pins, then swap bit_out and bit_in shifts in the GB_SET macro


#elif defined (__AVR_ATmega32U4__)
/***************************************************************************
* Arduino Leonardo/Yún/Micro (ATmega32U4)
***************************************************************************/
    #include <USB-MIDI.h>

    #define USE_LEONARDO
    #define HAS_USB_MIDI

    #define GB_SET(bit_cl, bit_out, bit_in) PORTF = (PINF & B00011111) | ((bit_cl << 7) | (bit_out << 6) | (bit_in << 5))
    // ^ The reason for not using digitalWrite is to align clock and data pins for the GB shift reg.
    // Pin distribution comes from official Arduino Leonardo documentation

    const int pinGBClock = A0;                       // Analog In 0 - clock out to gameboy
    const int pinGBSerialOut = A1;                   // Analog In 1 - serial data to gameboy
    const int pinGBSerialIn = A2;                    // Analog In 2 - serial data from gameboy
    const int pinMidiInputPower = 4;                 // power pin for midi input opto-isolator
    const int pinStatusLed = 13;                     // Status LED
    const int pinLeds[] = {12, 11, 10, 9, 8, 13};    // LED Pins
    const int pinButtonMode = 3;                     // toggle button for selecting the mode
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

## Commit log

2025-09-01 WIP: big overhaul. Created Promicroboy! rearraged, refactored, manual merges etc.
    see changelog.md
    [1u_panel.kicad_pcb, 3u_panel.kicad_pcb, link_breakout.kicad_pcb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]
2026-03-26 it compiles! completed manual merge / refactor of tstirrat and Chiptune-Anamnesis repo's (finally). also more code cleanup and consistency fixes. next commit will be bug fixes...
    [Arduinoboy.cpp, Led_Functions.cpp, MCU_Pin_Assignments.h]
2026-03-28 improved mode switching so it doesn't lag or get stuck anymore. also a little more code cleanup.
    [Arduinoboy.cpp, Led_Functions.cpp, Mode.cpp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]

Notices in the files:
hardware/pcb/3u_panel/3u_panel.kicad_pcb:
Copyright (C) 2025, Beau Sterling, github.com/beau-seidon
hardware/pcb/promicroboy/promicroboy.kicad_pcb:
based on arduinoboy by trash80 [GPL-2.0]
